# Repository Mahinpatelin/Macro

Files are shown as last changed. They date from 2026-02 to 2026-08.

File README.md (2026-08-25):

# Macro — Custom RP2040 Macropad

An end-to-end mechatronics build combining PCB design, embedded firmware, human-machine-interface design, and a 3D-printed enclosure. The device uses eight mechanical keys, an EC11 rotary encoder with push switch, an OLED header, and a Seeed Studio XIAO RP2040.

> Status: design package complete; fabrication outputs are included. Hardware behavior must be verified on the physical assembly before the design is treated as production-ready.

System architecture

## Engineering highlights

- Designed a custom 2 × 5 electrical key matrix in KiCad with one intentionally unpopulated matrix position.
- Added per-switch diodes to prevent ghosting during multi-key input.
- Integrated an RP2040 microcontroller, incremental encoder, encoder push switch, and I²C OLED connector.
- Implemented QMK firmware for key scanning, volume control, mute, and OLED status.
- Packaged Gerber fabrication files and an STL enclosure for reproducible manufacturing.
- Added an automated design audit that cross-checks PCB population against the QMK layout.

## Repository map

| Path | Purpose |
|---|---|
| `PCB/` | Editable KiCad schematic and PCB sources |
| `CAD/case.stl` | Printable enclosure mesh |
| `Production/gerbers.zip` | PCB manufacturing outputs |
| `macro_firmware/` | QMK keyboard definition and keymap |
| `docs/BOM.csv` | Bill of materials |
| `docs/DESIGN.md` | Requirements, architecture, and engineering decisions |
| `docs/BUILD_GUIDE.md` | Fabrication, assembly, flashing, and bring-up |
| `tools/design_audit.py` | PCB/firmware consistency checks |

## Quick validation

```bash
python3 tools/design_audit.py
```

The audit checks the eight Cherry MX footprints, encoder switch, nine diodes, matrix dimensions, and nine populated QMK positions. It does not replace electrical-rule checking, design-rule checking, or physical bring-up.

## Firmware build

1. Install the [QMK CLI](https://docs.qmk.fm/newbs_getting_started).
2. Copy `macro_firmware` into a keyboard folder in a QMK checkout.
3. Compile the default keymap for the RP2040 target.
4. Enter the XIAO RP2040 bootloader and copy the generated UF2 file to the board.

Exact commands depend on the folder name chosen inside the QMK tree. See [the build guide](docs/BUILD_GUIDE.md) before connecting hardware.

## Design correction documented in this version

The PCB contains eight Cherry MX switches plus the encoder push switch: nine physical buttons total. The original firmware layout declared all ten positions of the 2 × 5 matrix and assigned a key to the unpopulated position. This version models only the nine populated positions while retaining the 2 × 5 electrical matrix.

## Skills demonstrated

PCB design · embedded C · QMK · RP2040 · matrix scanning · design for manufacture · CAD-to-print workflow · engineering validation

## Safety and limitations

- Confirm polarity, continuity, and supply rails with a multimeter before inserting the microcontroller.
- Verify the OLED module voltage and pin order; common modules do not all share the same header order.
- Gerbers should be re-generated after any PCB source change.
- The included STL should be checked against the chosen printer, switch plate, fasteners, and tolerances.

## License

Original firmware, documentation, and project-specific design files are released under the MIT License. Third-party footprints, libraries, and tools retain their respective licenses.

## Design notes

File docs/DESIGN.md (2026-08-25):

# Engineering design record

## Requirements

| ID | Requirement | Verification |
|---|---|---|
| R1 | Provide eight independently programmable mechanical keys | PCB footprint audit and hardware key test |
| R2 | Provide a rotary input for volume adjustment | Encoder direction test |
| R3 | Use encoder press as mute | QMK keymap inspection and hardware test |
| R4 | Support a small I²C status display | Schematic inspection and display bring-up |
| R5 | Connect over USB using an RP2040 controller | Enumeration and key-report test |
| R6 | Fit inside a printable enclosure | CAD interference check and trial assembly |
| R7 | Be reproducible from repository artifacts | Fresh-clone build and manufacturing-file review |

## Architecture

The XIAO RP2040 scans a two-row, five-column matrix. Eight Cherry MX switches occupy columns 0–3 across both rows. The encoder push switch occupies row 0, column 4; row 1, column 4 is intentionally empty. Each button path includes a diode and the firmware declares `COL2ROW` direction.

The encoder quadrature channels connect separately to GPIO pins GP2 and GP1. The OLED connector uses I²C on GP6/GP7. USB supplies power and carries HID reports.

## Key decisions

### Matrix instead of direct GPIO

A matrix reduces the GPIO count and reflects standard keyboard practice. With per-key diodes, simultaneous presses can be distinguished without phantom keys.

### XIAO RP2040

The compact module provides native USB, sufficient GPIO, QMK support, and an accessible UF2 bootloader while avoiding the risk of designing the high-speed USB and MCU support circuitry directly onto the first PCB revision.

### Through-hole switches and diodes

Through-hole parts simplify hand assembly and rework. The tradeoff is a larger board and more manual soldering than a surface-mount production design.

### Firmware-to-PCB consistency audit

Hardware and firmware can fail silently when a matrix position exists in software but is not populated in hardware. `tools/design_audit.py` makes this interface explicit and is suitable for CI.

## Engineering follow-ups

- Add dimensioned enclosure drawings and tolerance callouts after measuring a printed prototype.
- Record current consumption with and without the OLED.
- Capture electrical-rule and design-rule check reports from the exact KiCad version used for release.
- Add ESD protection and a reset/boot access strategy if the design is revised for repeated field use.
- Replace placeholder USB VID/PID values before any commercial distribution.

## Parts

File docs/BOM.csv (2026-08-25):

Item | Reference | Quantity | Description | Selection note
1 | U1 | 1 | Seeed Studio XIAO RP2040 | Confirm castellated/header mounting approach
2 | SW2-SW9 | 8 | MX-compatible mechanical key switch | Choose consistent plate/PCB mount style
3 | SW1 | 1 | EC11E-style incremental rotary encoder with push switch | Confirm shaft and thread dimensions
4 | D1-D9 | 9 | Through-hole switching diode DO-35 | Observe polarity
5 | J1 | 1 | 1x4 2.54 mm OLED header | Verify display voltage and pin order
6 |  | 8 | MX-compatible keycaps | Match switch stem
7 |  | 1 | Encoder knob | Match shaft diameter/profile
8 |  | 1 | Custom PCB | Order from reviewed Gerbers
9 |  | 1 | 3D-printed enclosure | Verify material and fit experimentally
10 |  | 1 | USB cable | Data-capable cable required

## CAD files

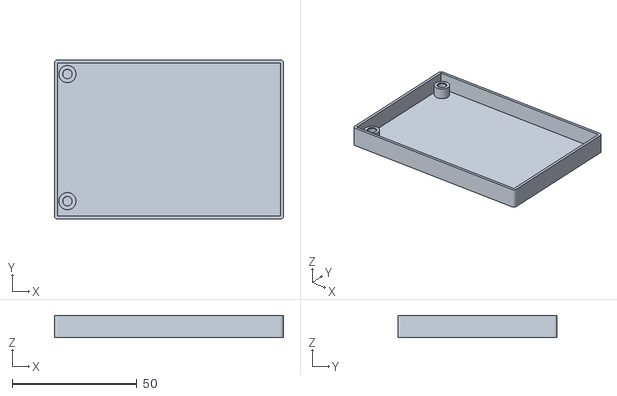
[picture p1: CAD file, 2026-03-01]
CAD/case.stl
91.9 x 63.9 x 9.00

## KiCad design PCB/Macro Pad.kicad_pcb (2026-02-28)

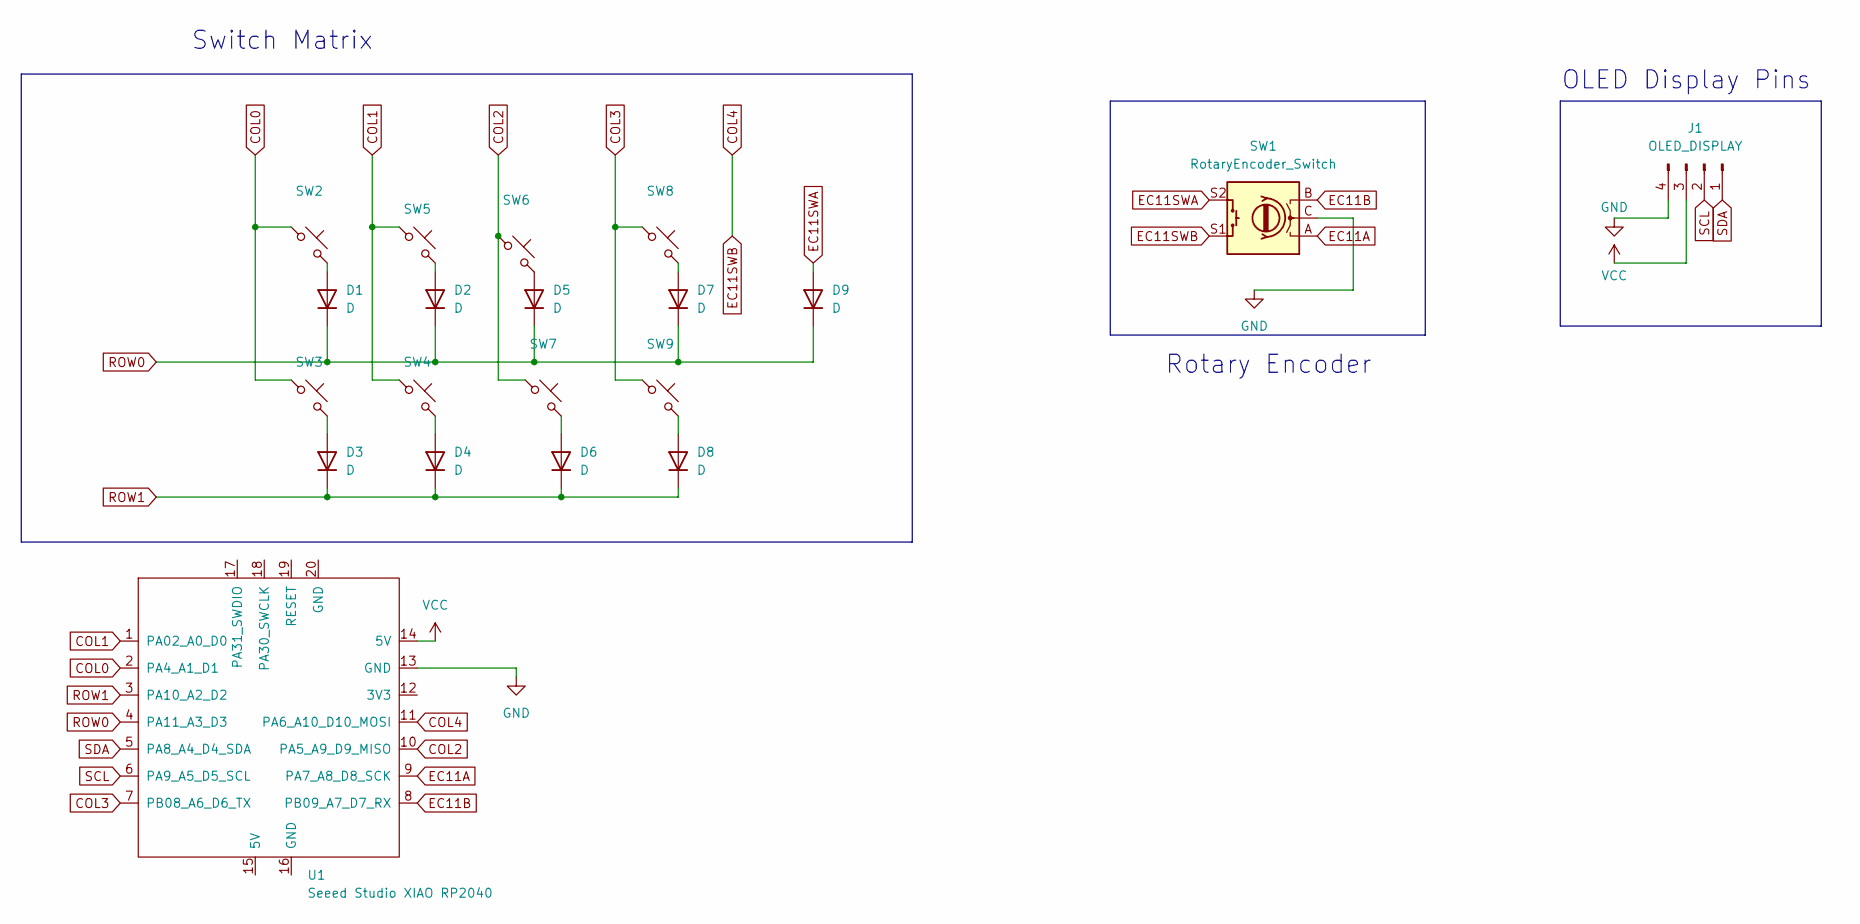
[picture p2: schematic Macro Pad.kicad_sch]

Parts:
D1, D2, D3, D4, D5, D6, D7, D8, D9: D; D_DO-35_SOD27_P7.62mm_Horizontal
J1: OLED_DISPLAY; PinHeader_1x04_P2.54mm_Vertical
SW1: RotaryEncoder_Switch; RotaryEncoder_Alps_EC11E-Switch_Vertical_H20mm
SW2, SW3, SW4, SW5, SW6, SW7, SW8, SW9: SW_Push_45deg; SW_Cherry_MX_1.00u_PCB
U1: Seeed Studio XIAO RP2040; XIAO-Generic-Hybrid-14P-2.54-21X17.8MM

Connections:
COL0: SW2.1, SW3.1, U1.2 (PA4_A1_D1)
COL1: SW4.1, SW5.1, U1.1 (PA02_A0_D0)
COL2: SW6.1, SW7.1, U1.10 (PA5_A9_D9_MISO)
COL3: SW8.1, SW9.1, U1.7 (PB08_A6_D6_TX)
COL4: SW1.S1, U1.11 (PA6_A10_D10_MOSI)
EC11A: SW1.A, U1.9 (PA7_A8_D8_SCK)
EC11B: SW1.B, U1.8 (PB09_A7_D7_RX)
EC11SWA: D9.2 (A), SW1.S2
GND: J1.4, SW1.C, U1.13 (GND)
unnamed: D1.2 (A), SW2.2
unnamed: D2.2 (A), SW5.2
unnamed: D3.2 (A), SW3.2
unnamed: D4.2 (A), SW4.2
unnamed: D5.2 (A), SW6.2
unnamed: D6.2 (A), SW7.2
unnamed: D7.2 (A), SW8.2
unnamed: D8.2 (A), SW9.2
ROW0: D1.1 (K), D2.1 (K), D5.1 (K), D7.1 (K), D9.1 (K), U1.4 (PA11_A3_D3)
ROW1: D3.1 (K), D4.1 (K), D6.1 (K), D8.1 (K), U1.3 (PA10_A2_D2)
SCL: J1.2, U1.6 (PA9_A5_D5_SCL)
SDA: J1.1, U1.5 (PA8_A4_D4_SDA)
VCC: J1.3, U1.14 (5V)

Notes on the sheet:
Switch Matrix
OLED Display Pins
Rotary Encoder

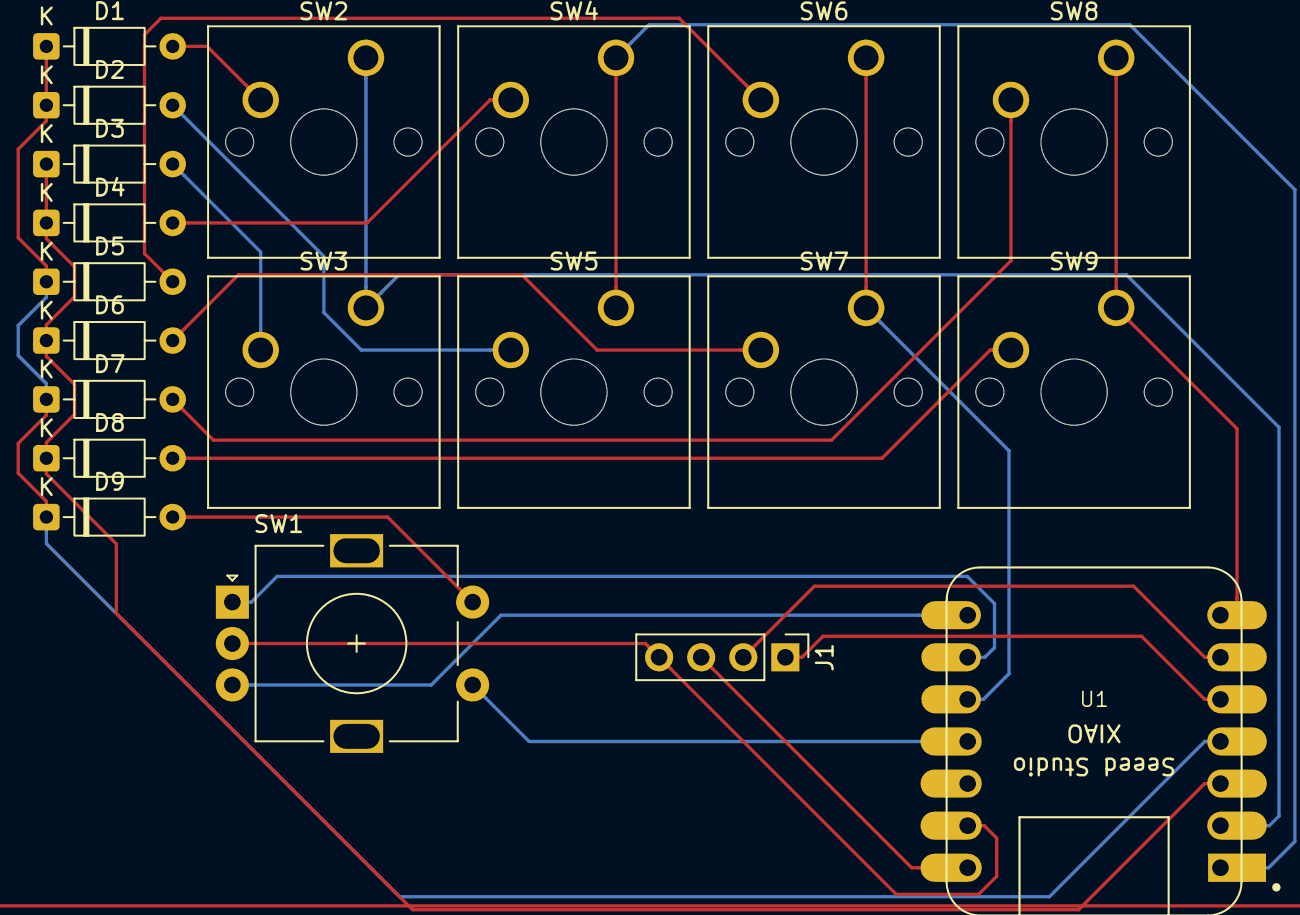
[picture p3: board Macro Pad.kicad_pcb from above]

Board: 2 copper layers, 20 parts (0 on the bottom side), 22 nets.

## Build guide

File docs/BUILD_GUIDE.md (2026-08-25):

# Build and bring-up guide

## 1. Review before ordering

1. Open the schematic and PCB in KiCad.
2. Run electrical-rule checking and design-rule checking.
3. Inspect switch orientation, diode polarity, XIAO orientation, OLED header order, board outline, holes, and copper clearances.
4. Compare the generated Gerbers with the editable PCB. Re-generate them if sources changed.

## 2. Suggested assembly order

1. Diodes, observing polarity.
2. Low-profile headers and connectors.
3. XIAO sockets or module headers.
4. Mechanical switches and encoder.
5. OLED header; attach the OLED only after rail checks.

Inspect every solder joint and remove flux residue as appropriate. Do not connect USB yet.

## 3. Electrical checks

- Confirm there is no short between power and ground.
- Confirm each diode conducts in one direction only.
- Confirm each switch closes the intended row/column path.
- Verify the OLED header pin order against the selected display module.

## 4. Firmware

Copy `macro_firmware` into a QMK keyboard directory and compile its default keymap. Flash the UF2 using the RP2040 bootloader. The default map is:

```text
Top electrical row:    1  2  3  4  Mute (encoder press)
Bottom electrical row: 5  6  7  8
Encoder rotation:      Volume down / volume up
```

## 5. Functional test

| Test | Expected result |
|---|---|
| USB enumeration | Host recognizes a keyboard |
| Eight switches | Keys 1–8 register once per press |
| Encoder clockwise | Volume increases |
| Encoder counterclockwise | Volume decreases |
| Encoder press | Mute toggles |
| OLED fitted | Status text appears without bus errors |

Record anomalies in an issue before changing both hardware and firmware at the same time.

## 6. Mechanical assembly

Slice `CAD/case.stl` using material-appropriate settings. Before a full print, verify the switch plate thickness, USB clearance, encoder height, and PCB mounting method. Use a first-article print to establish printer-specific fit compensation.

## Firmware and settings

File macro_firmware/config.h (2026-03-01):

#pragma once

// Makes the rotary encoder feel natural (1 click = 1 volume notch)
#define ENCODER_RESOLUTION 4

// OLED Settings for Seeed XIAO RP2040
#define I2C_DRIVER I2CD2
#define I2C1_SDA_PIN GP6
#define I2C1_SCL_PIN GP7

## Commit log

2026-08-25 Add engineering design package
    [BOM.csv]
2026-08-25 Add PCB to firmware design audit
